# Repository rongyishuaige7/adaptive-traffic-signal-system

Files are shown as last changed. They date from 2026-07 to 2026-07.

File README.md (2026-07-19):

# 车流量自适应交通信号控制系统

一个面向教学与本科毕业设计参考的桌面十字路口原型：四路 ESP32-CAM 提供 MJPEG 视频，后端使用 YOLOv8 / ByteTrack 跟踪并统计车流，FastAPI 与 Vue 3 工作台展示运行事实，主控 ESP32 驱动 12 路交通灯和 4 块 OLED。




> **使用提示：** 本项目用于桌面教学与技术学习，不能用于控制真实道路信号灯。

## 项目资料

这里整理了项目照片、界面截图和相关资料；文件处理说明见 [MEDIA_EVIDENCE](docs/MEDIA_EVIDENCE.md)。

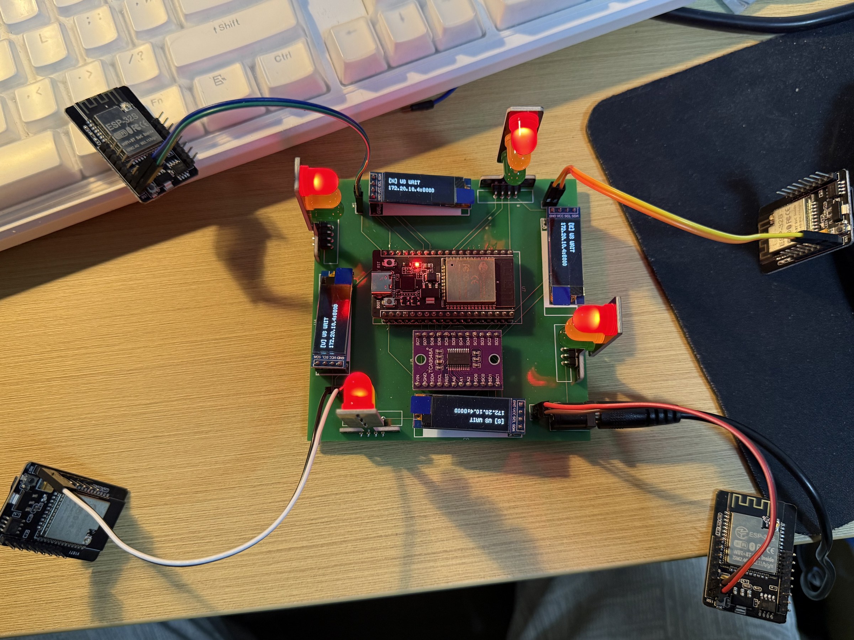
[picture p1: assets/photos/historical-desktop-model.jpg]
桌面交通信号教学模型，2026-05-14


## 项目能力

- 东、南、西、北四路 AI Thinker ESP32-CAM 固件，使用 DHCP 与 MJPEG 端点；
- 四路后端工作线程，基于 YOLOv8 / ByteTrack 跟踪车辆并统计虚拟线穿越次数；
- 南北、东西两相位状态机，以有界线性公式计算下一轮绿灯时间；
- FastAPI 状态接口、MJPEG 转发以及 UI / 设备 WebSocket；
- Vue 3 工作台分别展示 UI 连接、设备客户端数量和近期视频帧事实；
- 主控 ESP32 驱动 12 路灯光，并通过 TCA9548A 连接 4 块 SSD1306 OLED；
- 四路合成 MJPEG 源和终端主控模拟器，便于在无硬件时学习与验证；
- 从当前源码整理的 BOM 与接线边界。

## 系统架构

```text
ESP32-CAM 东/南/西/北 ── MJPEG ──┐
                                  ▼
                       FastAPI + YOLOv8/ByteTrack
                                  │
                    ┌─────────────┴────────────┐
                    │ UI WebSocket + MJPEG     │ 设备 WebSocket
                    ▼                          ▼
                 Vue 3 界面              ESP32 主控制器
                                              │          │
                                         12 路灯光    TCA9548A
                                                         │
                                                  4 × SSD1306
```

## 仓库结构

```text
backend/                 FastAPI、车流统计、配时与 WebSocket 服务
frontend/                Vue 3 / Element Plus / ECharts 工作台
firmware/esp32_cam/      东/南/西/北 AI Thinker ESP32-CAM 固件
firmware/esp32_main/     12 路灯光 + 4 块 OLED 的 ESP32 主控固件
simulator/               本地模拟摄像头与模拟主控工具
tests/                   不依赖硬件的后端与模拟器契约测试
hardware/                从源码整理的 BOM 与接线边界图
docs/                    部署、状态、验证与来源说明
scripts/                 敏感信息、仓库结构与完整验证门禁
```

## 快速验证

下面的一键门禁用于检查仓库结构与本地构建：

```bash
bash scripts/verify.sh
```

## 本地模拟

创建虚拟环境并安装开发依赖：

```bash
python3 -m venv .venv
. .venv/bin/activate
pip install -r backend/requirements-dev.txt
python simulator/fake_cam.py
```

默认模拟摄像头使用本机 `8181`–`8184` 端口。再分别从 `backend/` 和 `frontend/` 启动后端与前端：

```bash
# 后端终端
cd backend
cp .env.example .env
uvicorn app.main:app --host 127.0.0.1 --port 8000

# 前端终端
cd frontend
npm ci
npm run dev
```

可选的终端设备模拟器：

```bash
python simulator/fake_mcu.py --uri ws://127.0.0.1:8000/ws/device
```

完整视频工作线程还需要自行获取 YOLO 模型，见[模型配置与许可说明](docs/MODEL_SETUP.md)。

## 硬件配置

公开固件不包含真实 Wi-Fi 凭据或私有局域网地址。它可以使用空值或不可路由测试值完成构建，但在本地配置就绪前会在运行时拒绝启动网络链路。

- 将相应 `local-config.example.ini` 中的值复制到被忽略的本地 PlatformIO 配置，或通过环境构建参数提供；
- 除非已有明确的本地地址规划，否则 ESP32-CAM 保持 DHCP；
- 主控制器的 `PC_HOST` 只在本地配置中填写真实后端地址；
- 接线前按 [HARDWARE.md](HARDWARE.md) 核对精确板型、电压、限流、GPIO 和共地拓扑。

## 运行说明

- `GET /health` 只表示 **FastAPI 进程已响应**；
- `GET /api/runtime` 报告每个方向是否收到近期处理帧，以及 UI / 设备 WebSocket 客户端数量；
- 占位图始终明确表示 `no fresh frame`，不会被计为健康摄像头；

## 注意事项

- 不分发 YOLO 模型权重，使用与分发需遵守上游许可；
- HTTP、MJPEG 与 WebSocket 均无认证和 TLS；默认仅绑定本机，真机局域网联调必须显式启用并隔离；
- 设备协议没有认证身份、命令 ACK、实体灯光反馈、硬件互锁或冲突监测；
- 本项目绝不能用于控制真实道路信号灯。

## 文档

- [硬件与接线说明](HARDWARE.md)
- [部署与模拟](docs/DEPLOYMENT.md)
- [模型配置与许可说明](docs/MODEL_SETUP.md)
- [WebSocket 与状态协议](docs/PROTOCOL.md)
- [源码来源](docs/SOURCE_PROVENANCE.md)
- [验证记录](docs/VERIFICATION.md)
- [第三方声明](THIRD_PARTY_NOTICES.md)

## 许可证

本仓库原创材料采用 [MIT License](LICENSE)。依赖与模型权重继续适用各自许可，尤其应在 [THIRD_PARTY_NOTICES.md](THIRD_PARTY_NOTICES.md) 中核对 Ultralytics 的 AGPL-3.0 / Enterprise 边界。

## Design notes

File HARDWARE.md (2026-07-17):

# 硬件与接线边界

本文档是**根据当前源码整理的接线指南**，不是 EDA 原理图，也不能证明留存的五板实物已针对当前公开提交完成复测。

## ESP32 主控制器

| 方向 | 红灯 | 黄灯 | 绿灯 |
|:--|:--|:--|:--|
| 北 | GPIO13 | GPIO14 | GPIO27 |
| 南 | GPIO16 | GPIO17 | GPIO18 |
| 东 | GPIO19 | GPIO21 | GPIO22 |
| 西 | GPIO23 | GPIO25 | GPIO26 |

源码假定使用 4 个自带限流的三色灯模块。接线前必须确认真实模块的工作电压、极性和电阻值。GPIO14 是启动绑带引脚；部分带 PSRAM 的 ESP32-WROVER 板无法使用 GPIO16/17，因此必须根据实物确认主控模块的精确型号。

## 通过 TCA9548A 连接 4 块 OLED

| 功能 | 主控 ESP32 / 多路复用器 |
|:--|:--|
| SDA | GPIO4 |
| SCL | GPIO5 |
| TCA9548A 地址 | `0x70`，A0/A1/A2 接低电平 |
| 北向 OLED | 通道 0，SSD1306 `0x3C` |
| 南向 OLED | 通道 1，SSD1306 `0x3C` |
| 东向 OLED | 通道 2，SSD1306 `0x3C` |
| 西向 OLED | 通道 3，SSD1306 `0x3C` |

## ESP32-CAM 节点

固件使用 AI Thinker 摄像头引脚定义，并提供 `/`、`/jpg` 和 `/stream`。东南西北四个构建仅 `CAM_DIRECTION` 不同；公开默认使用 DHCP，Wi-Fi 与可选静态地址均属于本地忽略配置。

请为精确板型提供稳定电源；历史指南建议每个节点使用 5 V / 1 A。控制和显示模块按其供电拓扑要求共用参考地。

## 提升证据状态前必须确认

- 主控 ESP32 与 4 块 ESP32-CAM 的精确模块版本；
- 摄像头传感器型号；
- 显示屏和多路复用器模块；
- 交通灯模块的电压、极性和电阻值；
- 实际供电轨与共地拓扑；
- 当前实物接线是否逐项匹配上述 GPIO；
- WebSocket 断开后的全红行为是否真实反映在实体灯上。

另见[接线边界图](hardware/wiring-diagram.svg)和 [BOM](hardware/BOM.csv)。

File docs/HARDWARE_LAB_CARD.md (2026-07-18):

# Hardware Lab 项目卡

## 车流量自适应交通信号控制系统

由四路摄像头、YOLOv8 跟踪与计数、FastAPI、Vue 3、WebSocket 状态下发、ESP32 12 路灯光控制器和 4 块 OLED 组成的桌面交通信号教学原型。

- **平台：** ESP32-CAM × 4 · ESP32 · YOLOv8 · FastAPI · Vue 3 · WebSocket
- **构建验证：** 后端测试、前端生产构建、东南西北四路 ESP32-CAM 构建和主控 ESP32 构建通过
- **媒体：** 当前未公开真实硬件照片、演示视频、界面截图或 EDA / 制造文件
- **边界：** 模拟器和构建证据不代表检测准确率、实体灯光状态或道路安全；仅用于桌面教学

- **项目素材：** 已补充项目照片、界面截图和相关资料；范围和版本差异见 [`MEDIA_EVIDENCE.md`](MEDIA_EVIDENCE.md)。

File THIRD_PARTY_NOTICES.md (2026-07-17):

# 第三方声明

本仓库原创材料采用 MIT 许可证。仓库不内置模型权重、npm 包、Python 包源码、PlatformIO 包、字体或其完整源码树；这些第三方组件继续适用各自条款。

| 组件 | 用途 | 许可证 / 来源 |
|:--|:--|:--|
| Ultralytics | YOLOv8 检测与 ByteTrack 集成 | AGPL-3.0 或 Ultralytics Enterprise；<https://www.ultralytics.com/license> |
| Ultralytics 模型权重 | 用户首次运行或另行获取 | 本仓库不分发；使用或再分发前必须核对上述模型与软件条款 |
| OpenCV | 视频帧解码、标注与模拟器图像 | Apache-2.0；<https://opencv.org/license/> |
| FastAPI / Starlette / Uvicorn | 后端 HTTP 与 WebSocket 服务 | MIT / BSD-3-Clause；见上游包仓库 |
| Pydantic / pydantic-settings | 环境配置 | MIT；<https://github.com/pydantic/pydantic> |
| NumPy | 图像数组操作 | BSD-3-Clause；<https://numpy.org/> |
| aiohttp | 四路摄像头模拟器 | Apache-2.0；<https://github.com/aio-libs/aiohttp> |
| websockets | 模拟器客户端与后端依赖 | BSD-3-Clause；<https://github.com/python-websockets/websockets> |
| Rich | 终端主控模拟器 | MIT；<https://github.com/Textualize/rich> |
| Vue 3 | 前端框架 | MIT；<https://github.com/vuejs/core> |
| Element Plus | 前端组件 | MIT；<https://github.com/element-plus/element-plus> |
| Apache ECharts | 车流图表 | Apache-2.0；<https://github.com/apache/echarts> |
| Vite / TypeScript | 前端构建工具链 | MIT / Apache-2.0；见上游仓库 |
| Arduino-ESP32 / Espressif platform | ESP32 与 ESP32-CAM 固件框架 | LGPL-2.1 及组件各自条款；<https://github.com/espressif/arduino-esp32> |
| arduinoWebSockets | ESP32 设备 WebSocket 客户端 | LGPL-2.1；<https://github.com/Links2004/arduinoWebSockets> |
| ArduinoJson | 设备端 JSON 解析 | MIT；<https://github.com/bblanchon/ArduinoJson> |
| U8g2 | SSD1306 显示 | BSD-2-Clause；<https://github.com/olikraus/u8g2> |

Ultralytics 是本项目最重要的许可边界：Rongyi 原创源码的 MIT 许可证不能替代 AGPL-3.0 或适用的企业许可证。任何分发或服务化使用都应重新核对上游现行条款。

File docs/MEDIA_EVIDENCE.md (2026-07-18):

# 项目素材说明

> 整理日期：2026-07-18

## 文件来源与处理

- 本地 Hardware Lab 素材中心保留原始文件；本仓库收录适合公开展示的处理后副本。
- 图片已按需要移除元数据、遮盖私有信息或缩放；具体处理方式见下表。

## 已公开文件

| 公开路径 | 拍摄日期 / 来源日期 | 脱敏处理 | 文件说明 |
|:--|:--|:--|:--|
| `assets/photos/historical-desktop-model.jpg` | 2026-05-14 | 已移除 EXIF/GPS 及其他图片元数据；从副本缩放处理 | 桌面教学模型照片；不是道路部署证据。 |
| `assets/screenshots/historical-dashboard.jpg` | 2026-05-14 | 已移除 EXIF/GPS 及其他图片元数据；从副本缩放处理 | 仪表盘截图；显示计数不证明检测器准确度或实体灯状态。 |
| `hardware/eda/schematic.pdf` | 2026-07-18 提供的导出文件 | 从副本移除 PDF 元数据 | 面向桌面教学模型的EDA 导出；未获道路控制批准或验证。 |
| `hardware/eda/pcb-preview.pdf` | 2026-07-18 提供的导出文件 | 从副本移除 PDF 元数据 | 面向桌面教学模型的EDA 导出；未获道路控制批准或验证。 |
| `hardware/eda/bom-export.csv` | 2026-07-18 提供的导出文件 | 从 UTF-16LE 表格导出转换为 UTF-8 CSV；已省略供应商、店铺和价格字段 | 面向桌面教学模型的EDA 导出；未获道路控制批准或验证。 |
| `hardware/eda/gerber/` | 2026-07-18 提供的导出文件 | 从副本解包 Gerber/钻孔成员；已省略第三方下单说明文本 | 面向桌面教学模型的EDA 导出；未获道路控制批准或验证。 |

## 未公开材料

未列于上表的文件没有复制到本仓库。常见原因包括重复或错投文件、私人标识、过时界面语义或接线信息不完整。原始文件仍保留在本地素材中心。

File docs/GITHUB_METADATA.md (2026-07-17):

# GitHub 元数据

- **仓库：** `adaptive-traffic-signal-system`
- **简介：** `四路 ESP32-CAM + YOLOv8 车流统计、FastAPI/Vue 3 工作台与 ESP32 交通灯控制器组成的桌面教学原型。`
- **Topics：** `esp32`, `esp32-cam`, `yolov8`, `fastapi`, `vue3`, `websocket`, `computer-vision`, `traffic-signal`, `iot`, `hardware-project`
- **默认分支：** `main`

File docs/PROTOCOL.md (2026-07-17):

# WebSocket 与状态契约

## UI WebSocket

- 端点：`/ws/ui`
- 服务端到 UI：重复发送 `state` JSON
- 当前后端忽略客户端消息

## 设备 WebSocket

- 端点：`/ws/device`
- 服务端到设备：发送相同的 `state` JSON
- 设备到服务端：当前固件会发送心跳 JSON 供调试，但不会被当作已认证 ACK

状态示例：

```json
{
  "type": "state",
  "phase": "NS_GREEN",
  "remain_s": 8,
  "total_s": 10,
  "yellow_s": 3,
  "flow_per_min": {"N": 0, "S": 0, "E": 0, "W": 0},
  "traffic": {},
  "ws_clients": {"ui": 1, "device": 0},
  "green_ns_next": 10,
  "green_ew_next": 10
}
```

`ws_clients.device > 0` 只表示存在一个或多个 WebSocket 连接；它不能证明客户端身份、ESP32 已正确启动、JSON 已执行、LED 已变化、OLED 已更新或系统处于安全信号状态。

## HTTP 事实

| 端点 | 准确含义 |
|:--|:--|
| `GET /health` | 只表示 FastAPI 进程存活并响应 |
| `GET /api/status` | 当前进程内状态机载荷与已观察计数 |
| `GET /api/runtime` | 配置开关、各方向近期视频帧事实与 WebSocket 连接数量 |
| `GET /api/traffic` | 各方向最新的内存计数快照 |
| `GET /api/video/{N,S,E,W}.mjpg` | 标注视频流，或明确的等待占位图 |

本教学协议没有认证、TLS、设备身份、消息签名、防重放、命令确认或实体反馈。

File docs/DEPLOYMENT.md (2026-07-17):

# 部署与模拟

## 安全的本地模拟

```bash
python3 -m venv .venv
. .venv/bin/activate
pip install -r backend/requirements-dev.txt
python simulator/fake_cam.py
```

在另一个终端进入 `backend/`：

```bash
cp .env.example .env
uvicorn app.main:app --host 127.0.0.1 --port 8000
```

然后启动前端：

```bash
cd frontend
npm ci
npm run dev
```

合成摄像头用于验证传输和界面链路，它不包含已标注车辆，也不能作为硬件证据。完整后端还需要按 [MODEL_SETUP.md](MODEL_SETUP.md) 在本地提供 YOLO 权重。

如需在没有 ESP32 的情况下观察设备消息：

```bash
python simulator/fake_mcu.py --uri ws://127.0.0.1:8000/ws/device
```

## 可信局域网真机联调

1. 将 `backend/.env.example` 复制为被忽略的 `backend/.env`，再把模拟地址替换为真实摄像头端点；
2. 同机使用时继续让后端绑定本机。只有其他实体设备确实需要连接时才启用局域网绑定，并通过防火墙限制在隔离可信网络；
3. 通过未跟踪的 PlatformIO 本地配置或环境构建参数提供 Wi-Fi 凭据及真实后端 / 摄像头地址，绝不能写入已提交源码；
4. 分别构建并烧录东南西北四路摄像头和主控制器，再按 [VERIFICATION.md](VERIFICATION.md) 对精确提交执行真机检查清单。

当前协议没有认证和 TLS。不要把后端、摄像头流或 WebSocket 暴露到公网，也绝不能连接真实道路信号灯。

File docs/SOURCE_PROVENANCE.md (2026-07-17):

# 源码来源

## 权威副本裁决

| 对象 | 角色 | 证据 | 规则 |
|:--|:--|:--|:--|
| `/mnt/shared/2026项目/车流量自适应的交通信号控制系统_源码.tar.gz` | 只读历史基线 | SHA-256 `df48d6619b8558c23917f8735d54b4e7d19cb891f112edebd42314d74ec19e09`；修改时间 2026-05-06 | 不编辑、不重打包 |
| `/home/rongyi/桌面/车流量自适应的交通信号控制系统` | 较新的权威源码 | 文件日期最晚到 2026-05-16，并包含更晚的部署指南；顶层 `.git` 为空 | 只读来源，不在原地清理 |
| `/home/rongyi/桌面/adaptive-traffic-signal-system` | 干净公开候选 | 使用明确复制排除项和全新公开 Git 历史 | 所有公开加固只在此目录实施 |

名称相近的 `/home/rongyi/桌面/基于esp32s3交通摄像` 是另一个 ESP32-S3 双板项目，没有合并到本仓库。

## 合并与排除记录

从较新的桌面源码纳入：

- FastAPI 后端、Vue 3 前端与两个固件项目；
- 协议及从源码整理的接线信息；
- package lock 与 PlatformIO 依赖声明。

仅从历史归档审查后纳入：

- `simulator/fake_cam.py` 与 `simulator/fake_mcu.py`；
- 空的 `samples/.gitkeep` 占位文件。

首次提交前排除：

- 空的 `.git/` 目录和全部编辑器配置；
- 含历史摄像头地址的 `backend/.env`；
- 全部模型权重，包括约 6.5 MB 的 nano 权重和 87.8 MB 的 large 权重；
- `frontend/node_modules/`、`frontend/dist/`、Python 缓存与字节码；
- 历史归档固件中的 Wi-Fi 凭据；
- 生成的 PlatformIO 产物与私有静态地址配置。

## 公开加固

- 默认后端、模拟器与 CORS 只允许本机；
- 凭据与真实局域网端点只存在于本地构建配置；
- 公开矩阵中的摄像头固件默认使用 DHCP；
- 不提交模型权重；
- 用窄口径的进程存活、视频帧与客户端连接事实替代全局 `ok` 状态；
- 前端明确区分 UI WebSocket、设备客户端数量与视频流新鲜度；
- 非法视频方向拒绝处理；
- 补充配时边界、计数、状态语义、合成图像和 WebSocket 数量测试。

以上变更已经源码与构建验证，但不能证明当前五板硬件行为或真实道路适用性。

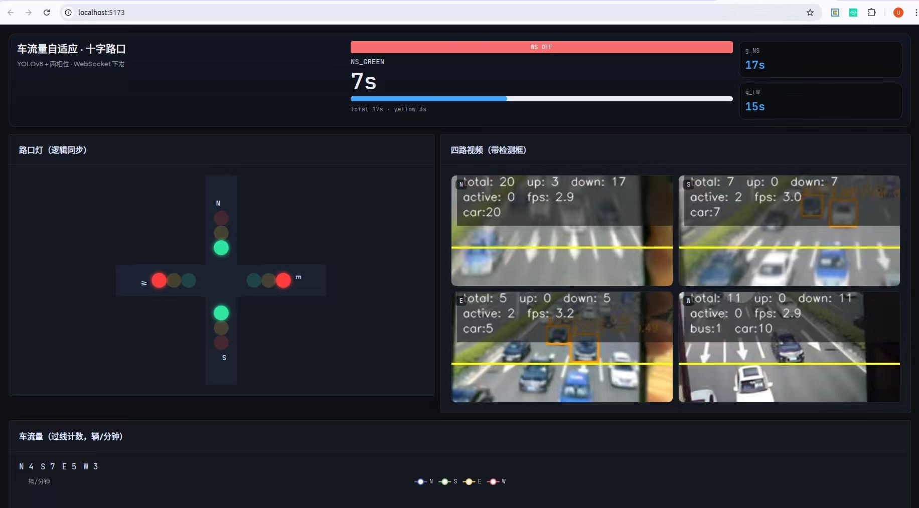
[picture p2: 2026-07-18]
assets/screenshots/historical-dashboard.jpg

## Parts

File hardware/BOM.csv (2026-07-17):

Designator | Item | Quantity | Source-confirmed specification | Needs physical confirmation | Notes
CAM-N..W | ESP32-CAM board | 4 | AI Thinker pin map in firmware | Exact module and camera sensor | One stream per direction
CAMERA-N..W | Camera module | 4 | ESP32 camera JPEG stream | OV2640 or other exact sensor | Do not infer model from board name alone
MCU | ESP32 main controller | 1 | PlatformIO esp32dev target | Exact module and WROOM/WROVER variant | GPIO16/17 conflict with WROVER PSRAM
LIGHT-N..W | Three-color traffic light module | 4 | 12 LED control signals total | Module voltage and resistor values | Source document says module includes limiting resistors
OLED-N..W | SSD1306 OLED 128x32 | 4 | I2C address 0x3C | Exact panel voltage and dimensions | One display per direction
MUX | TCA9548A I2C multiplexer | 1 | Address 0x70 with A0/A1/A2 low | Exact breakout board | Channels 0 through 3 used
PSU-CAM | Regulated camera supply | 4 | 5 V and 1 A per camera recommended | Actual supply ratings | Prevent brownouts during Wi-Fi streaming
PSU-MCU | Controller and display supply | 1 | Shared logic supply and common ground | Actual rating and wiring | Confirm module voltage requirements
WIRE | Jumpers and common ground | as needed | GPIO and I2C connections in HARDWARE.md | Wire gauge and connectors | Verify against retained prototype
MODEL | Tabletop intersection model | 1 | Four-direction teaching scene | Dimensions and construction | Not included as a digital design asset

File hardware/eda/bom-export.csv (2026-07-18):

name | designator | footprint | quantity | part_number | manufacturer
DC 5.5*2.1 | DC1 | DC-005-20A | 1 | DC-005-20A | HRO
2pin排针 | H1,H2,H3,H4 | 2PIN排针 | 4 | A2541WV-9P | Changjiang Connectors
0.91寸OLED液晶显示屏模块 | U1,U2,U3,U4 | 0.91寸OLED液晶显示屏模块 | 4
WJ_TCA9548A | U5 | TCA9548A | 1
LED交通信号灯模块 | U6,U8,U9,U10 | LED交通信号灯模块 | 4
ESP32-DevKitC | U7 | ESP32-DEVKIT-C | 1 | ESP32-WROOM-32 | Espressif Systems

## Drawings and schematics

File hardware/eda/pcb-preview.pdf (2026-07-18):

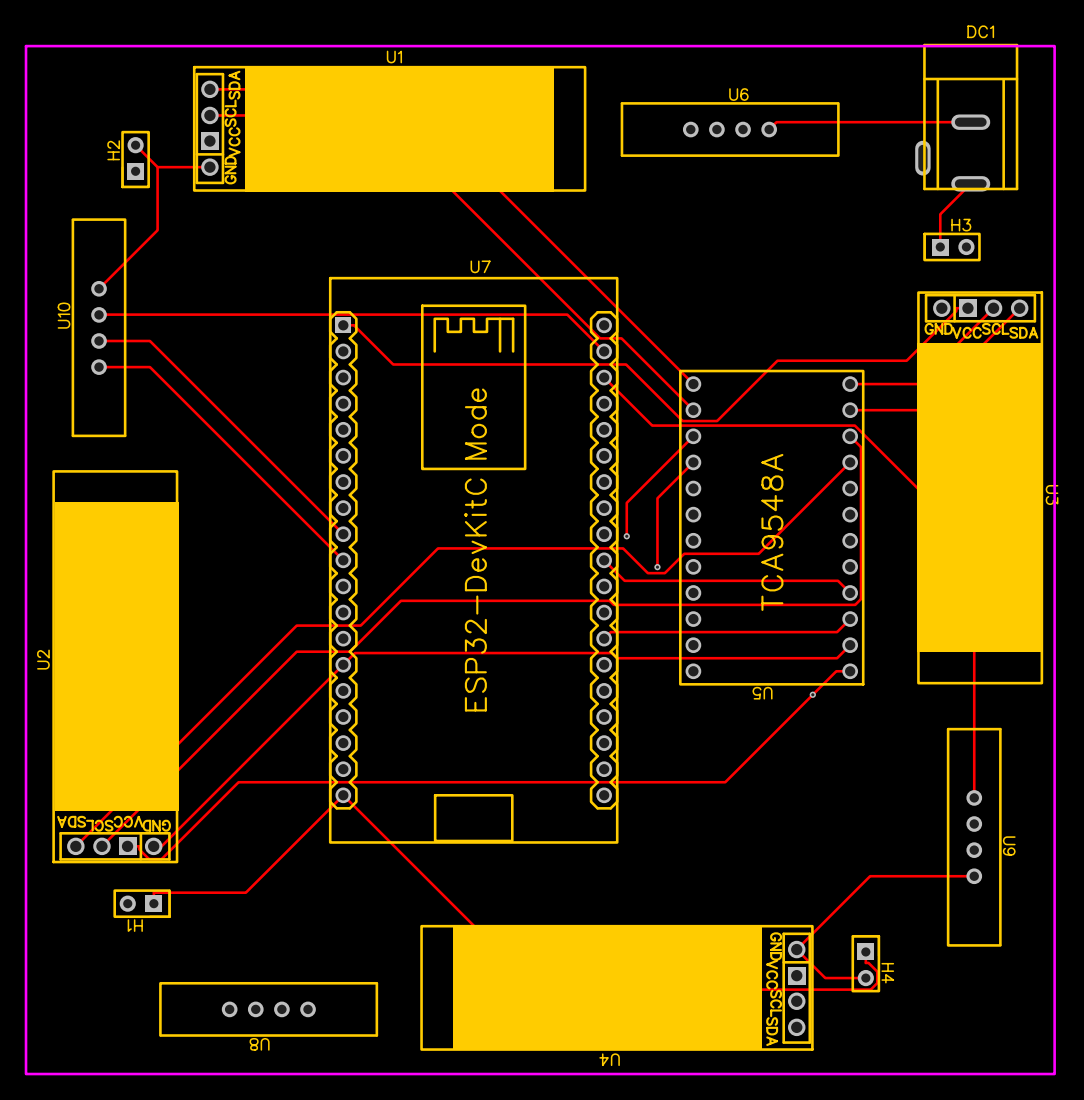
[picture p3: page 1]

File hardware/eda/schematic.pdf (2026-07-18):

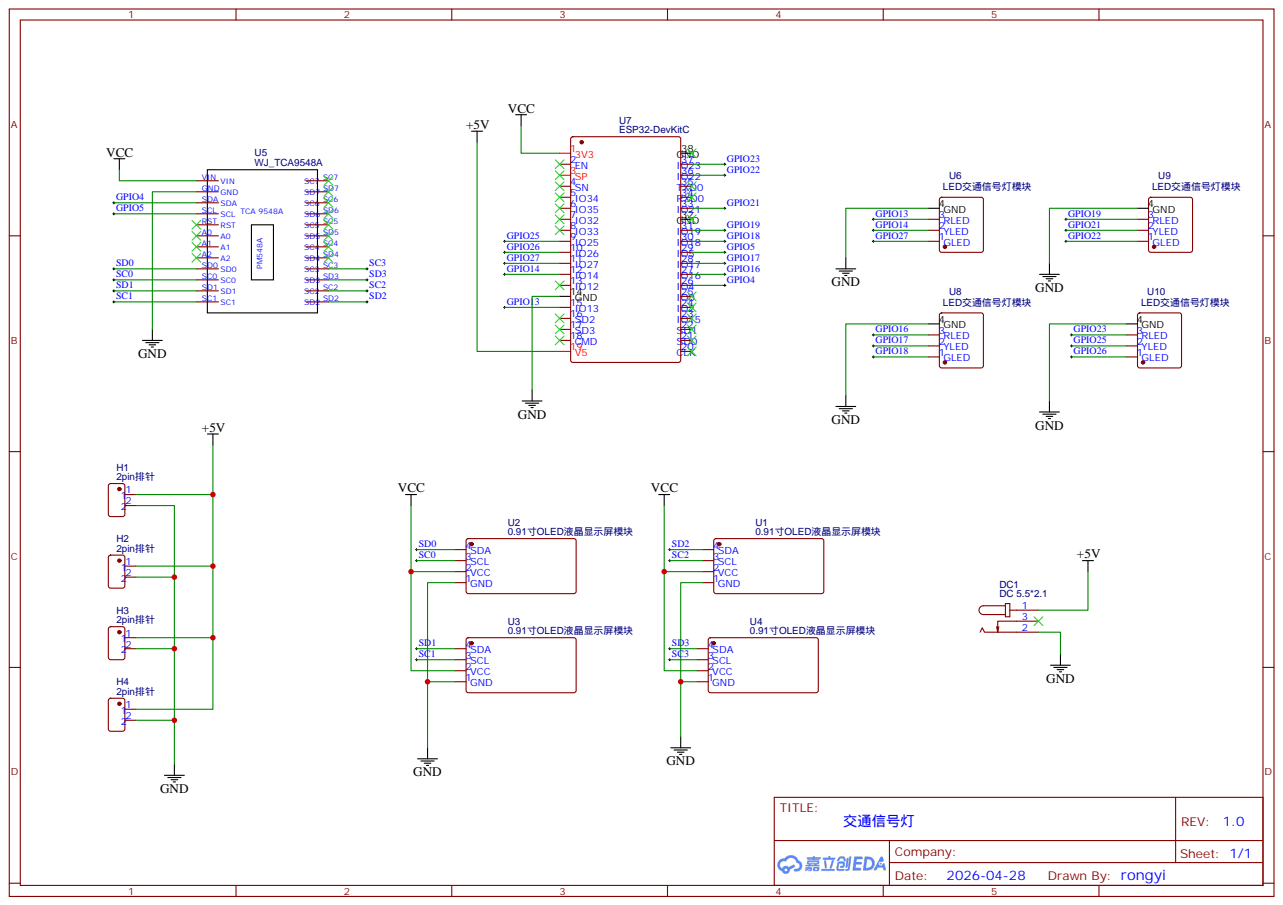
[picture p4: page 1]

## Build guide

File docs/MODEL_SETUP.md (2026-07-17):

# YOLO 模型配置

模型权重有意不存入 Git。

后端默认使用 `YOLO_MODEL=yolov8n.pt`。安装 Ultralytics 后，首次使用可能会将对应上游权重下载到本地缓存或当前环境；也可以在被忽略的 `backend/.env` 中把 `YOLO_MODEL` 指向本地已核验文件。

下载或再分发权重前：

1. 核对当前 [Ultralytics 许可证](https://www.ultralytics.com/license)；
2. 记录实验所用 Ultralytics 精确版本、模型文件名、来源 URL 与文件哈希；
3. 除非许可和来源已经独立核清，否则不要把权重提交到 Git 或 Release；
4. 不要把上游预训练模型当成本桌面场景检测准确率的证据。

CI 只运行模拟与硬件无关的契约，不会下载权重文件。

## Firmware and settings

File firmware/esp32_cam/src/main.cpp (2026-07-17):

/**
 * ESP32-CAM (AI Thinker): WiFi + MJPEG /stream + mDNS.
 * Per device: set WIFI_SSID, WIFI_PASS, CAM_DIRECTION (N/S/E/W).
 */
#include <Arduino.h>
#include <WiFi.h>
#include "esp_camera.h"
#include "esp_http_server.h"
#include "img_converters.h"
#include "esp_heap_caps.h"
#include <ESPmDNS.h>

#ifndef CAM_DIRECTION
#define CAM_DIRECTION "N"
#endif
#ifndef WIFI_SSID
#define WIFI_SSID ""
#endif
#ifndef WIFI_PASS
#define WIFI_PASS ""
#endif
#ifdef STATIC_IP
#ifndef STATIC_GW
#error "STATIC_GW is required when STATIC_IP is set"
#endif
#ifndef STATIC_SUBNET
#error "STATIC_SUBNET is required when STATIC_IP is set"
#endif
#ifndef STATIC_DNS
#define STATIC_DNS STATIC_GW
#endif
#endif
#ifndef CAMERA_FRAME_SIZE
#define CAMERA_FRAME_SIZE FRAMESIZE_QVGA
#endif
#ifndef CAMERA_JPEG_QUALITY
#define CAMERA_JPEG_QUALITY 14
#endif
#ifndef STREAM_FRAME_DELAY_MS
#define STREAM_FRAME_DELAY_MS 150
#endif

#define PART_BOUNDARY "123456789000000000000987654321"
static const char *_STREAM_CONTENT_TYPE =
    "multipart/x-mixed-replace;boundary=" PART_BOUNDARY;
static const char *_STREAM_BOUNDARY = "\r\n--" PART_BOUNDARY "\r\n";
static const char *_STREAM_PART =
    "Content-Type: image/jpeg\r\nContent-Length: %u\r\n\r\n";

#if defined(CAMERA_MODEL_AI_THINKER)
#define PWDN_GPIO_NUM 32
#define RESET_GPIO_NUM -1
#define XCLK_GPIO_NUM 0
#define SIOD_GPIO_NUM 26
#define SIOC_GPIO_NUM 27
#define Y9_GPIO_NUM 35
#define Y8_GPIO_NUM 34
#define Y7_GPIO_NUM 39
#define Y6_GPIO_NUM 36
#define Y5_GPIO_NUM 21
#define Y4_GPIO_NUM 19
#define Y3_GPIO_NUM 18
#define Y2_GPIO_NUM 5
#define VSYNC_GPIO_NUM 25
#define HREF_GPIO_NUM 23
#define PCLK_GPIO_NUM 22
#endif

static httpd_handle_t stream_httpd = NULL;

static bool parse_ip(IPAddress &ip, const char *value, const char *name) {
  if (ip.fromString(value))
    return true;
  Serial.printf("Invalid %s: %s\n", name, value);
  return false;
}

static void configure_wifi_ip() {
  Serial.print("MAC: ");
  Serial.println(WiFi.macAddress());

#ifdef STATIC_IP
  IPAddress local_ip;
  IPAddress gateway;
  IPAddress subnet;
  IPAddress dns;
  if (!parse_ip(local_ip, STATIC_IP, "STATIC_IP") ||
      !parse_ip(gateway, STATIC_GW, "STATIC_GW") ||
      !parse_ip(subnet, STATIC_SUBNET, "STATIC_SUBNET") ||
      !parse_ip(dns, STATIC_DNS, "STATIC_DNS")) {
    Serial.println("Static IP disabled because config is invalid");
    return;
  }

  if (WiFi.config(local_ip, gateway, subnet, dns)) {
    Serial.print("Static IP configured: ");
    Serial.println(local_ip);
  } else {
    Serial.println("Static IP config failed, fallback to DHCP");
  }
#else
  Serial.println("IP config: DHCP");
#endif
}

static bool test_camera_capture(const char *tag) {
  for (int i = 0; i < 5; i++) {
    camera_fb_t *fb = esp_camera_fb_get();
    if (fb) {
      Serial.printf("%s: capture OK, %ux%u, len=%u\n", tag,
                    (unsigned)fb->width, (unsigned)fb->height,
                    (unsigned)fb->len);
      esp_camera_fb_return(fb);
      return true;
    }
    Serial.printf("%s: capture failed, retry %d\n", tag, i + 1);
    delay(300);
  }
  return false;
}

static esp_err_t index_handler(httpd_req_t *req) {
  static const char html[] =
      "<!doctype html><html><head><meta name=\"viewport\" "
      "content=\"width=device-width,initial-scale=1\">"
      "<title>ESP32-CAM</title></head><body>"
      "<h3>ESP32-CAM</h3>"
      "<p><a href=\"/jpg\">Single JPG</a></p>"
      "<p><a href=\"/stream\">MJPEG stream</a></p>"
      "</body></html>";
  httpd_resp_set_type(req, "text/html");
  httpd_resp_set_hdr(req, "Access-Control-Allow-Origin", "*");
  return httpd_resp_send(req, html, HTTPD_RESP_USE_STRLEN);
}

static esp_err_t jpg_handler(httpd_req_t *req) {
  camera_fb_t *fb = esp_camera_fb_get();
  if (!fb) {
    Serial.println("JPG: camera_fb_get failed");
    httpd_resp_send_500(req);
    return ESP_FAIL;
  }

  esp_err_t res = ESP_OK;
  if (fb->format == PIXFORMAT_JPEG) {
    httpd_resp_set_type(req, "image/jpeg");
    httpd_resp_set_hdr(req, "Access-Control-Allow-Origin", "*");
    res = httpd_resp_send(req, (const char *)fb->buf, fb->len);
  } else {
    uint8_t *jpg_buf = NULL;
    size_t jpg_len = 0;
    bool ok = frame2jpg(fb, 15, &jpg_buf, &jpg_len);
    if (ok) {
      httpd_resp_set_type(req, "image/jpeg");
      httpd_resp_set_hdr(req, "Access-Control-Allow-Origin", "*");
      res = httpd_resp_send(req, (const char *)jpg_buf, jpg_len);
      free(jpg_buf);
    } else {
      Serial.println("JPG: frame2jpg failed");
      httpd_resp_send_500(req);
      res = ESP_FAIL;
    }
  }

  esp_camera_fb_return(fb);
  return res;
}

static esp_err_t stream_handler(httpd_req_t *req) {
  camera_fb_t *fb = NULL;
  esp_err_t res = ESP_OK;
  char part_buf[64];
  uint32_t frame_count = 0;

  Serial.println("STREAM: client connected");

  res = httpd_resp_set_type(req, _STREAM_CONTENT_TYPE);
  if (res != ESP_OK)
    return res;
  httpd_resp_set_hdr(req, "Access-Control-Allow-Origin", "*");

  while (true) {
    size_t jpg_len = 0;
    uint8_t *jpg_buf = NULL;
    fb = esp_camera_fb_get();
    if (!fb) {
      Serial.println("STREAM: camera_fb_get failed");
      res = ESP_FAIL;
      break;
    }
    if (fb->format != PIXFORMAT_JPEG) {
      bool ok = frame2jpg(fb, 12, &jpg_buf, &jpg_len);
      esp_camera_fb_return(fb);
      fb = NULL;
      if (!ok) {
        res = ESP_FAIL;
        break;
      }
    } else {
      jpg_len = fb->len;
      jpg_buf = fb->buf;
    }

    if (res == ESP_OK)
      res = httpd_resp_send_chunk(req, _STREAM_BOUNDARY,
                                    strlen(_STREAM_BOUNDARY));
    if (res == ESP_OK) {
      size_t hlen =
          snprintf(part_buf, sizeof(part_buf), _STREAM_PART, (unsigned)jpg_len);
      res = httpd_resp_send_chunk(req, part_buf, hlen);
    }
    if (res == ESP_OK)
      res = httpd_resp_send_chunk(req, (const char *)jpg_buf, jpg_len);

    if (fb) {
      esp_camera_fb_return(fb);
      fb = NULL;
    } else if (jpg_buf) {
      free(jpg_buf);
      jpg_buf = NULL;
    }
    frame_count++;
    if (frame_count == 1 || frame_count % 100 == 0) {
      Serial.printf("STREAM: sent %u frames\n", (unsigned)frame_count);
    }
    if (res != ESP_OK)
      break;
    delay(STREAM_FRAME_DELAY_MS);
  }
  Serial.printf("STREAM: client disconnected, res=0x%x, frames=%u\n",
                (unsigned)res, (unsigned)frame_count);
  return res;
}

static esp_err_t start_stream_server() {
  httpd_config_t config = HTTPD_DEFAULT_CONFIG();
  config.server_port = 80;
  config.ctrl_port = 32768;
  config.stack_size = 8192;

  if (httpd_start(&stream_httpd, &config) != ESP_OK)
    return ESP_FAIL;

  httpd_uri_t index_uri = {.uri = "/",
                           .method = HTTP_GET,
                           .handler = index_handler,
                           .user_ctx = NULL};
  if (httpd_register_uri_handler(stream_httpd, &index_uri) != ESP_OK)
    return ESP_FAIL;

  httpd_uri_t stream_uri = {.uri = "/stream",
                            .method = HTTP_GET,
                            .handler = stream_handler,
                            .user_ctx = NULL};
  if (httpd_register_uri_handler(stream_httpd, &stream_uri) != ESP_OK)
    return ESP_FAIL;

  httpd_uri_t jpg_uri = {.uri = "/jpg",
                         .method = HTTP_GET,
                         .handler = jpg_handler,
                         .user_ctx = NULL};
  if (httpd_register_uri_handler(stream_httpd, &jpg_uri) != ESP_OK)
    return ESP_FAIL;
  return ESP_OK;
}

void setup() {
  Serial.begin(115200);
  Serial.setDebugOutput(false);
  setCpuFrequencyMhz(160);
  delay(200);

  camera_config_t config = {};
  config.ledc_channel = LEDC_CHANNEL_0;
  config.ledc_timer = LEDC_TIMER_0;
  config.pin_d0 = Y2_GPIO_NUM;
  config.pin_d1 = Y3_GPIO_NUM;
  config.pin_d2 = Y4_GPIO_NUM;
  config.pin_d3 = Y5_GPIO_NUM;
  config.pin_d4 = Y6_GPIO_NUM;
  config.pin_d5 = Y7_GPIO_NUM;
  config.pin_d6 = Y8_GPIO_NUM;
  config.pin_d7 = Y9_GPIO_NUM;
  config.pin_xclk = XCLK_GPIO_NUM;
  config.pin_pclk = PCLK_GPIO_NUM;
  config.pin_vsync = VSYNC_GPIO_NUM;
  config.pin_href = HREF_GPIO_NUM;
  config.pin_sccb_sda = SIOD_GPIO_NUM;
  config.pin_sccb_scl = SIOC_GPIO_NUM;
  config.pin_pwdn = PWDN_GPIO_NUM;
  config.pin_reset = RESET_GPIO_NUM;
  config.xclk_freq_hz = 20000000;
  config.pixel_format = PIXFORMAT_JPEG;
  config.frame_size = CAMERA_FRAME_SIZE;
  config.jpeg_quality = CAMERA_JPEG_QUALITY;
  config.fb_count = 1;
  config.fb_location = psramFound() ? CAMERA_FB_IN_PSRAM : CAMERA_FB_IN_DRAM;
  config.grab_mode = CAMERA_GRAB_WHEN_EMPTY;
  config.sccb_i2c_port = 0;

  Serial.printf("Free heap: %u, free PSRAM: %u\n",
                (unsigned)ESP.getFreeHeap(),
                (unsigned)heap_caps_get_free_size(MALLOC_CAP_SPIRAM));
  Serial.println("Camera init...");
  esp_err_t err = esp_camera_init(&config);
  if (err != ESP_OK) {
    Serial.printf("Camera init failed 0x%x\n", err);
    while (true)
      delay(1000);
  }
  Serial.println("Camera OK");
  if (!test_camera_capture("Camera self-test")) {
    Serial.println("Camera self-test failed");
    while (true)
      delay(1000);
  }
  delay(1000);

  Serial.println("WiFi mode...");
  WiFi.persistent(false);
  WiFi.mode(WIFI_STA);
  configure_wifi_ip();
  WiFi.setSleep(false);
  WiFi.setTxPower(WIFI_POWER_2dBm);
  delay(500);
  if (strlen(WIFI_SSID) == 0) {
    Serial.println("WiFi credentials not configured; copy local-config.example.ini to local-config.ini");
    while (true)
      delay(1000);
  }
  WiFi.begin(WIFI_SSID, WIFI_PASS);
  Serial.print("WiFi");
  unsigned long wifiStart = millis();
  while (WiFi.status() != WL_CONNECTED && millis() - wifiStart < 30000) {
    delay(500);
    Serial.print(".");
  }
  if (WiFi.status() != WL_CONNECTED) {
    Serial.println();
    Serial.println("WiFi connect timeout");
    while (true)
      delay(1000);
  }
  Serial.println();
  Serial.print("IP: ");
  Serial.println(WiFi.localIP());

  char host[32];
  snprintf(host, sizeof(host), "traffic-cam-%s", CAM_DIRECTION);
  if (MDNS.begin(host)) {
    Serial.printf("mDNS: %s.local\n", host);
    MDNS.addService("http", "tcp", 80);
  }

  Serial.println("HTTP start...");
  if (start_stream_server() != ESP_OK) {
    Serial.println("HTTP start failed");
    while (true)
      delay(1000);
  }
  Serial.print("Open: http://");
  Serial.println(WiFi.localIP());
  Serial.print("MJPEG: http://");
  Serial.print(WiFi.localIP());
  Serial.println("/stream");
  Serial.print("JPG: http://");
  Serial.print(WiFi.localIP());
  Serial.println("/jpg");
}

void loop() { delay(1000); }

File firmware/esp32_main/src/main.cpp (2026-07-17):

/**
 * ESP32 main: 12 traffic LEDs + 4x 0.91" SSD1306 via TCA9548A (I2C SDA=4 SCL=5) + WebSocket client.
 * TCA9548A addr=0x70 (A0/A1/A2 to GND). OLED_N=CH0, OLED_S=CH1, OLED_E=CH2, OLED_W=CH3.
 * Set WIFI_SSID, WIFI_PASS, PC_HOST (IP of FastAPI PC), PC_PORT.
 */
#include <Arduino.h>
#include <WiFi.h>
#include <WebSocketsClient.h>
#include <Wire.h>
#include <ArduinoJson.h>
#include <U8g2lib.h>

#ifndef WIFI_SSID
#define WIFI_SSID ""
#endif
#ifndef WIFI_PASS
#define WIFI_PASS ""
#endif
#ifndef PC_HOST
#define PC_HOST "127.0.0.1"
#endif
#ifndef PC_PORT
#define PC_PORT 8000
#endif

// GPIO map — see docs/wiring.md
#define PIN_N_R 13
#define PIN_N_Y 14
#define PIN_N_G 27  // was 15 (strapping pin, LED 下拉会影响启动)
#define PIN_S_R 16
#define PIN_S_Y 17
#define PIN_S_G 18
#define PIN_E_R 19
#define PIN_E_Y 21
#define PIN_E_G 22
#define PIN_W_R 23
#define PIN_W_Y 25
#define PIN_W_G 26

#define OLED_SDA 4
#define OLED_SCL 5

// TCA9548A I2C multiplexer — default address when A0/A1/A2 all GND
#define TCA9548A_ADDR 0x70
// Channel assignments: each OLED shares address 0x3C, distinguished by channel
#define TCA_CH_N 0
#define TCA_CH_S 1
#define TCA_CH_E 2
#define TCA_CH_W 3

// Four identical OLED instances — each activated via tcaSelect() before use
U8G2_SSD1306_128X32_UNIVISION_F_HW_I2C u8g2_N(U8G2_R0, U8X8_PIN_NONE);
U8G2_SSD1306_128X32_UNIVISION_F_HW_I2C u8g2_S(U8G2_R0, U8X8_PIN_NONE);
U8G2_SSD1306_128X32_UNIVISION_F_HW_I2C u8g2_E(U8G2_R0, U8X8_PIN_NONE);
U8G2_SSD1306_128X32_UNIVISION_F_HW_I2C u8g2_W(U8G2_R0, U8X8_PIN_NONE);

WebSocketsClient ws;

static String g_phase = "NS_GREEN";
static int g_remain = 0;
static int g_total = 0;
static int g_yellow = 3;
static int flowN = 0, flowS = 0, flowE = 0, flowW = 0;
static unsigned long lastHb = 0;
static bool wsConnected = false;

// Switch TCA9548A to the given channel (0-7). Pass 0xFF to disable all channels.
static void tcaSelect(uint8_t channel) {
  Wire.beginTransmission(TCA9548A_ADDR);
  Wire.write(channel > 7 ? 0x00 : (1 << channel));
  Wire.endTransmission();
}

static void allLedsOff() {
  const int pins[] = {PIN_N_R, PIN_N_Y, PIN_N_G, PIN_S_R, PIN_S_Y, PIN_S_G,
                      PIN_E_R, PIN_E_Y, PIN_E_G, PIN_W_R, PIN_W_Y, PIN_W_G};
  for (int p : pins)
    digitalWrite(p, LOW);
}

static void applyPhase(const String &ph) {
  allLedsOff();
  if (ph == "NS_GREEN") {
    digitalWrite(PIN_N_G, HIGH);
    digitalWrite(PIN_S_G, HIGH);
    digitalWrite(PIN_E_R, HIGH);
    digitalWrite(PIN_W_R, HIGH);
  } else if (ph == "NS_YELLOW") {
    digitalWrite(PIN_N_Y, HIGH);
    digitalWrite(PIN_S_Y, HIGH);
    digitalWrite(PIN_E_R, HIGH);
    digitalWrite(PIN_W_R, HIGH);
  } else if (ph == "EW_GREEN") {
    digitalWrite(PIN_E_G, HIGH);
    digitalWrite(PIN_W_G, HIGH);
    digitalWrite(PIN_N_R, HIGH);
    digitalWrite(PIN_S_R, HIGH);
  } else if (ph == "EW_YELLOW") {
    digitalWrite(PIN_E_Y, HIGH);
    digitalWrite(PIN_W_Y, HIGH);
    digitalWrite(PIN_N_R, HIGH);
    digitalWrite(PIN_S_R, HIGH);
  } else {
    // safe: all red
    digitalWrite(PIN_N_R, HIGH);
    digitalWrite(PIN_S_R, HIGH);
    digitalWrite(PIN_E_R, HIGH);
    digitalWrite(PIN_W_R, HIGH);
  }
}

// Draw one OLED: dir="N"/"S"/"E"/"W", myFlow=本方向流量, oppFlow=对向流量
static void drawOneOled(U8G2_SSD1306_128X32_UNIVISION_F_HW_I2C &disp,
                        uint8_t tcaCh, const char *dir, int myFlow,
                        int oppFlow) {
  tcaSelect(tcaCh);
  disp.clearBuffer();
  disp.setFont(u8g2_font_6x12_tf);

  // Line 1: direction + phase + countdown
  char line1[32];
  if (wsConnected) {
    snprintf(line1, sizeof(line1), "[%s] %s %ds", dir, g_phase.c_str(),
             g_remain);
  } else {
    snprintf(line1, sizeof(line1), "[%s] WS WAIT", dir);
  }
  disp.drawStr(0, 12, line1);

  // Line 2: this direction flow / opposite flow
  char line2[32];
  if (wsConnected) {
    snprintf(line2, sizeof(line2), "me:%d/min op:%d/min", myFlow, oppFlow);
  } else {
    snprintf(line2, sizeof(line2), "%s:%d", PC_HOST, PC_PORT);
  }
  disp.drawStr(0, 28, line2);

  disp.sendBuffer();
}

static void drawOled() {
  // North: opposite is South
  drawOneOled(u8g2_N, TCA_CH_N, "N", flowN, flowS);
  // South: opposite is North
  drawOneOled(u8g2_S, TCA_CH_S, "S", flowS, flowN);
  // East: opposite is West
  drawOneOled(u8g2_E, TCA_CH_E, "E", flowE, flowW);
  // West: opposite is East
  drawOneOled(u8g2_W, TCA_CH_W, "W", flowW, flowE);
}

void onWsEvent(WStype_t type, uint8_t *payload, size_t length) {
  if (type == WStype_TEXT) {
    JsonDocument doc;
    DeserializationError err = deserializeJson(doc, payload, length);
    if (err)
      return;
    const char *t = doc["type"] | "";
    if (strcmp(t, "state") != 0)
      return;
    const char *ph = doc["phase"] | "NS_GREEN";
    g_phase = String(ph);
    g_remain = doc["remain_s"] | 0;
    g_total = doc["total_s"] | 0;
    g_yellow = doc["yellow_s"] | 3;
    if (doc["flow_per_min"].is<JsonObject>()) {
      JsonObject f = doc["flow_per_min"];
      flowN = f["N"] | 0;
      flowS = f["S"] | 0;
      flowE = f["E"] | 0;
      flowW = f["W"] | 0;
    }
    applyPhase(g_phase);
    drawOled();
  } else if (type == WStype_CONNECTED) {
    wsConnected = true;
    Serial.println("WS connected");
    drawOled();
  } else if (type == WStype_DISCONNECTED) {
    wsConnected = false;
    Serial.println("WS disconnected");
    allLedsOff();
    digitalWrite(PIN_N_R, HIGH);
    digitalWrite(PIN_S_R, HIGH);
    digitalWrite(PIN_E_R, HIGH);
    digitalWrite(PIN_W_R, HIGH);
    drawOled();
  } else if (type == WStype_ERROR) {
    wsConnected = false;
    Serial.println("WS error");
    drawOled();
  }
}

void setup() {
  Serial.begin(115200);
  const int pins[] = {PIN_N_R, PIN_N_Y, PIN_N_G, PIN_S_R, PIN_S_Y, PIN_S_G,
                      PIN_E_R, PIN_E_Y, PIN_E_G, PIN_W_R, PIN_W_Y, PIN_W_G};
  for (int p : pins) {
    pinMode(p, OUTPUT);
    digitalWrite(p, LOW);
  }
  allLedsOff();
  digitalWrite(PIN_N_R, HIGH);
  digitalWrite(PIN_S_R, HIGH);
  digitalWrite(PIN_E_R, HIGH);
  digitalWrite(PIN_W_R, HIGH);

  Wire.begin(OLED_SDA, OLED_SCL);

  // Init all four OLEDs through TCA9548A
  tcaSelect(TCA_CH_N); u8g2_N.begin();
  tcaSelect(TCA_CH_S); u8g2_S.begin();
  tcaSelect(TCA_CH_E); u8g2_E.begin();
  tcaSelect(TCA_CH_W); u8g2_W.begin();
  drawOled();

  WiFi.mode(WIFI_STA);
  if (strlen(WIFI_SSID) == 0 || strcmp(PC_HOST, "127.0.0.1") == 0) {
    Serial.println("WiFi/PC host not configured; provide untracked local build flags");
    while (true)
      delay(1000);
  }
  WiFi.begin(WIFI_SSID, WIFI_PASS);
  while (WiFi.status() != WL_CONNECTED) {
    delay(500);
    Serial.print(".");
  }
  Serial.println(WiFi.localIP());

  ws.onEvent(onWsEvent);
  Serial.print("WS target: ws://");
  Serial.print(PC_HOST);
  Serial.print(":");
  Serial.print(PC_PORT);
  Serial.println("/ws/device");
  ws.begin(PC_HOST, PC_PORT, "/ws/device");
  ws.setReconnectInterval(3000);
  ws.enableHeartbeat(15000, 3000, 2);
}
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

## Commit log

2026-07-17 Open source adaptive traffic signal prototype
    [BOM.csv]
2026-07-18 docs: add sanitized historical project materials
    [Drill_PTH_Through.DRL, Drill_PTH_Through_Via.DRL, Gerber_BoardOutlineLayer.GKO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]
2026-07-18 docs: translate historical material evidence to Chinese
2026-07-18 docs: present project photos as project materials
2026-07-19 docs: 优化项目作品集介绍

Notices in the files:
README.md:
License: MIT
